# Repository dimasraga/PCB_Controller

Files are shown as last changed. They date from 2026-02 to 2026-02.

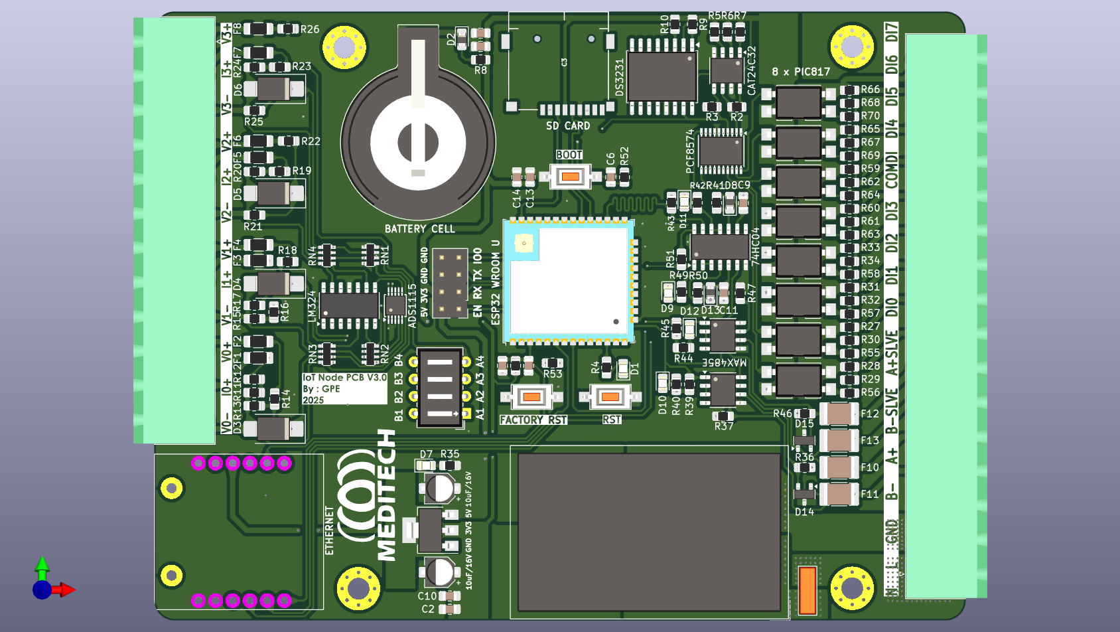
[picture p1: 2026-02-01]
3D PCB.png

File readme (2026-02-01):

# PCB IoT Node - Tugas Akhir

## 📖 Deskripsi Proyek

Repositori ini berisi file desain perangkat keras (Schematic & PCB Layout) dan dokumentasi untuk **IoT Node**. Proyek ini dikembangkan sebagai bagian dari **Tugas Akhir** di Departemen Teknik Elektro, Institut Teknologi Sepuluh Nopember (ITS).

PCB ini dirancang untuk berfungsi sebagai node sensor/aktuator dalam sistem Internet of Things, dengan fokus pada efisiensi daya dan konektivitas yang handal.

## 👤 Penulis

**Dimas Raga**
*   **Institusi:** Teknik Elektro, Institut Teknologi Sepuluh Nopember (ITS)
*   **GitHub:** https://github.com/dimasraga
*   **Instagram:** https://www.instagram.com/dmsragaa

## 📄 Lisensi

Proyek ini dilisensikan di bawah lisensi MIT - lihat file LICENSE untuk detailnya.

---
*Dibuat untuk memenuhi persyaratan Tugas Akhir Teknik Elektro ITS.*

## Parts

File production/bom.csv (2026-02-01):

Designator | Footprint | Quantity | Value | LCSC Part #
BT1 | BatteryHolder_Keystone_103_1x20mm | 1 | Battery_Cell
C1, C12, C4, C5, C6 | 0805 | 5 | 100nF | C1711
C10, C2 | 0805 | 2 | 100n | C1711
C11, C9 | 0805 | 2 | 33p | C541516
C13 | 0805 | 1 | 10uF | C1711
C14 | 0805 | 1 | 0.1uF | C1711
C3 | J_SD_Card-micro_socket_A | 1 | L-KLS1-TF-003-H1.85-R
C7, C8 | CP_Elec_4x5.8 | 2 | 10uF/16V | C59932
D1, D16 | LED_D3.0mm | 2 | Led Red | C2295
D10 | 0805 | 1 | RX | C2296
D11 | 0805 | 1 | TX | C2296
D12 | 0805 | 1 | RX_Slave | C2296
D13, D2, D8 | 0805 | 3 | 1N4148 | C85057
D14, D15 | SOT-23 | 2 | SM712_SOT23 | C32677
D3, D4, D5, D6 | D_SMB_Handsoldering | 4 | TVS_SMBJ28A | C113997
D7 | LED_D3.0mm | 1 | LED | C2297
D9 | 0805 | 1 | TX_Slave | C2296
F1, F2, F3, F4, F5, F6, F7, F8 | 1206 | 8 | 150 mA | C20797
F10, F11, F12, F13 | 1812 | 4 | Fuse_Small | C12430
F9 | C_Rect_L7.0mm_W2.5mm_P5.00mm | 1 | 1A/250VAC
J1 | PhoenixContact_MSTBA_2,5_16-G-5,08_1x16_P5.08mm_Horizontal | 1 | Screw_Terminal_01x16
J3 | PinHeader_2x04_P2.54mm_Vertical | 1 | UPLOADER
J4 | PhoenixContact_MSTBA_2,5_12-G-5,08_1x12_P5.08mm_Horizontal | 1 | Screw_Terminal_01x12
PS1 | Converter_ACDC_Hi-Link_HLK-5Mxx | 1 | HLK-5M05 | C209907
R1, R36, R37, R46, R47, R52, R53 | 0805 | 7 | 10K | C17414
R10, R2, R3, R39, R43, R45, R5, R51, R6, R7, R9 | 0805 | 11 | 4.7K | C26022
R11, R15, R19, R23 | 0805 | 4 | 100 | C2828765
R13, R14, R17, R18, R21, R22, R25, R26 | 0805 | 8 | 510k | C17733
R27, R28, R31, R33, R59, R60, R65, R66 | 0805 | 8 | 1M | C26115
R29, R30, R32, R34, R55, R56, R57, R58, R61, R62, R63, R64, R67, R68, R69, R70 | 0805 | 16 | 470 | C317246
R35, R4, R54, R8 | 0805 | 4 | 200 | C17540
R38, R48 | 1206 | 2 | 120 | C17909
R40, R42, R44, R49 | 0805 | 4 | 2.4k | C17526
R41, R50 | 0805 | 2 | 56k | C137509
RN1, RN2, RN3, RN4 | R_Array_Convex_4x0603 | 4 | 10k
SW1 | SW_SPST_CK_RS282G05A3 | 1 | RST | C231329
SW2 | SW_DIP_SPSTx04_Slide_6.7x11.72mm_W7.62mm_P2.54mm_LowProfile | 1 | SW_DIP_x04 | C840579
SW3 | SW_SPST_CK_RS282G05A3 | 1 | BOOT | C231329
SW4 | SW_Tactile_SPST_Angled_PTS645Vx58-2LFS | 1 | FACTORY RST | C231329
U1 | ESP32-WROOM-32U | 1 | ESP32-WROOM-32U | C328062
U11 | SOT-223-3_TabPin2 | 1 | AMS1117-33 | C6186
U12 | SSOP-20_4.4x6.5mm_P0.65mm | 1 | PCF8574ATS
U13 | TSSOP-10_3x3mm_P0.5mm | 1 | ADS1115IDGS | C37593
U14, U16 | SOIC-8_3.9x4.9mm_P1.27mm | 2 | MAX485E | C19738
U15 | SOIC-14_3.9x8.7mm_P1.27mm | 1 | 74HC04 | C6811
U17, U5 | SMDIP-4_W9.53mm_Clearance8mm | 2 | PC817 | C2833077
U18, U19, U20, U6, U7, U8 | SMDIP-4_W9.53mm_Clearance8mm | 6 | PIC817 | C2833077
U2 | SOIC-8_3.9x4.9mm_P1.27mm | 1 | CAT24C32WI-G | C81193
U3 | SOIC-16W_7.5x10.3mm_P1.27mm | 1 | DS3231SN# | C9866
U4 | SOIC-14_L8.7-W3.9-P1.27-LS6.0-BL | 1 | LM324 | C7943
U9 | W5500 | 1 | W5500_V2

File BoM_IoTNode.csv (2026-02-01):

Reference | Value | Footprint | Qty
BT1 | Battery_Cell | Battery:BatteryHolder_ComfortableElectronic_CH273-2450_1x2450 | 1
C1,C4,C5,C12 | 100nF | -- mixed values -- | 4
C2,C10 | 100n | Capacitor_SMD:C_0805_2012Metric_Pad1.18x1.45mm_HandSolder | 2
C3 | L-KLS1-TF-003-H1.85-R | Connector_Card:J_SD_Card-micro_socket_A | 1
C7,C8 | 10uF/16V | Capacitor_SMD:CP_Elec_4x5.8 | 2
C9,C11 | 33p | Capacitor_SMD:C_0805_2012Metric_Pad1.18x1.45mm_HandSolder | 2
D1 | Led Red | LED_SMD:LED_0805_2012Metric | 1
D2,D8,D13 | 1N4148 | Diode_THT:D_DO-35_SOD27_P7.62mm_Horizontal | 3
D3,D4,D5,D6 | TVS_SMBJ28A | Diode_SMD:D_SMB_Handsoldering | 4
D7 | LED | LED_SMD:LED_0805_2012Metric | 1
D9 | TX_Slave | LED_SMD:LED_0805_2012Metric | 1
D10 | RX | LED_SMD:LED_0805_2012Metric | 1
D11 | TX | LED_SMD:LED_0805_2012Metric | 1
D12 | RX_Slave | LED_SMD:LED_0805_2012Metric | 1
D14,D15 | SM712_SOT23 | Package_TO_SOT_SMD:SOT-23 | 2
F1,F2,F3,F4,F5,F6,F7,F8 | 150 mA | Resistor_SMD:R_1206_3216Metric_Pad1.30x1.75mm_HandSolder | 8
F9 | 1A/250VAC | Capacitor_THT:C_Rect_L7.0mm_W2.5mm_P5.00mm | 1
F10,F11,F12,F13 | Fuse_Small | Fuse:Fuse_1812_4532Metric_Pad1.30x3.40mm_HandSolder | 4
J2 | USB_B_Mini | Connector_USB:USB_Mini-B_Lumberg_2486_01_Horizontal | 1
J3,J4 | Screw_Terminal_01x12 | Connector_Phoenix_MSTB:PhoenixContact_MSTBA_2,5_12-G-5,08_1x12_P5.08mm_Horizontal | 2
PS1 | HLK-5M05 | IC SOIC:CONV_HLK-5M05 | 1
Q1,Q2 | BC817 | Package_TO_SOT_SMD:SOT-23 | 2
R1,R54 | 10K | Resistor_SMD:R_0805_2012Metric | 2
R2,R3,R5,R6,R7,R9,R10 | 4.7K | Resistor_SMD:R_0805_2012Metric | 7
R4,R8,R35 | 200 | -- mixed values -- | 3
R11,R15,R19,R23 | 240 | Resistor_SMD:R_0805_2012Metric_Pad1.20x1.40mm_HandSolder | 4
R12,R16,R24 | 10 | Resistor_SMD:R_0805_2012Metric_Pad1.20x1.40mm_HandSolder | 3
R13,R14,R17,R18,R21,R22,R25,R26 | 510k | Resistor_SMD:R_0805_2012Metric_Pad1.20x1.40mm_HandSolder | 8
R27,R28,R31,R33,R59,R60,R65,R66 | 1M | Resistor_SMD:R_0805_2012Metric | 8
R29,R30,R32,R34,R55,R56,R57,R58,R61,R62,R63,R64,R67,R68,R69,R70 | 470 | Resistor_SMD:R_0805_2012Metric | 16
R36,R37,R46,R47,R52,R53,RN1,RN2,RN3,RN4 | 10k | -- mixed values -- | 10
R38,R48 | 120 | Resistor_SMD:R_1206_3216Metric_Pad1.30x1.75mm_HandSolder | 2
R39,R43,R45,R51 | 4.7k | Resistor_SMD:R_0805_2012Metric_Pad1.20x1.40mm_HandSolder | 4
R40,R42,R44,R49 | 2.4k | Resistor_SMD:R_0805_2012Metric_Pad1.20x1.40mm_HandSolder | 4
R41,R50 | 56k | Resistor_SMD:R_0805_2012Metric_Pad1.20x1.40mm_HandSolder | 2
SW1,SW3 | SW_SPST | Button_Switch_SMD:SW_SPST_B3U-1000P | 2
SW2 | SW_DIP_x04 | Button_Switch_THT:SW_DIP_SPSTx04_Slide_6.7x11.72mm_W7.62mm_P2.54mm_LowProfile | 1
U1 | ESP32-WROOM-32U | RF_Module:ESP32-WROOM-32U | 1
U2 | CAT24C32WI-G | IC SOIC:SOIC127P600X175-8N | 1
U3 | DS3231SN# | IC SOIC:SOIC127P1032X265-16N | 1
U4 | LM324 | IC SOIC:SOIC127P600X175-14N | 1
U5,U17 | PC817 | Package_DIP:SMDIP-4_W9.53mm_Clearance8mm | 2
U6,U7,U8,U18,U19,U20 | PIC817 | Package_DIP:SMDIP-4_W9.53mm_Clearance8mm | 6
U9 | W5500_V2 | TTL to RS485:W5500 | 1
U10 | CH340C | Package_SO:SOIC-16_3.9x9.9mm_P1.27mm | 1
U11 | AMS1117-33 | Package_TO_SOT_SMD:SOT-223-3_TabPin2 | 1
U12 | PCF8574ATS | Package_SO:SSOP-20_4.4x6.5mm_P0.65mm | 1
U13 | ADS1115IDGS | Package_SO:TSSOP-10_3x3mm_P0.5mm | 1
U14,U16 | MAX485E | Package_SO:SOIC-8_3.9x4.9mm_P1.27mm | 2
U15 | 74HC04 | Package_SO:SOIC-14_3.9x8.7mm_P1.27mm | 1

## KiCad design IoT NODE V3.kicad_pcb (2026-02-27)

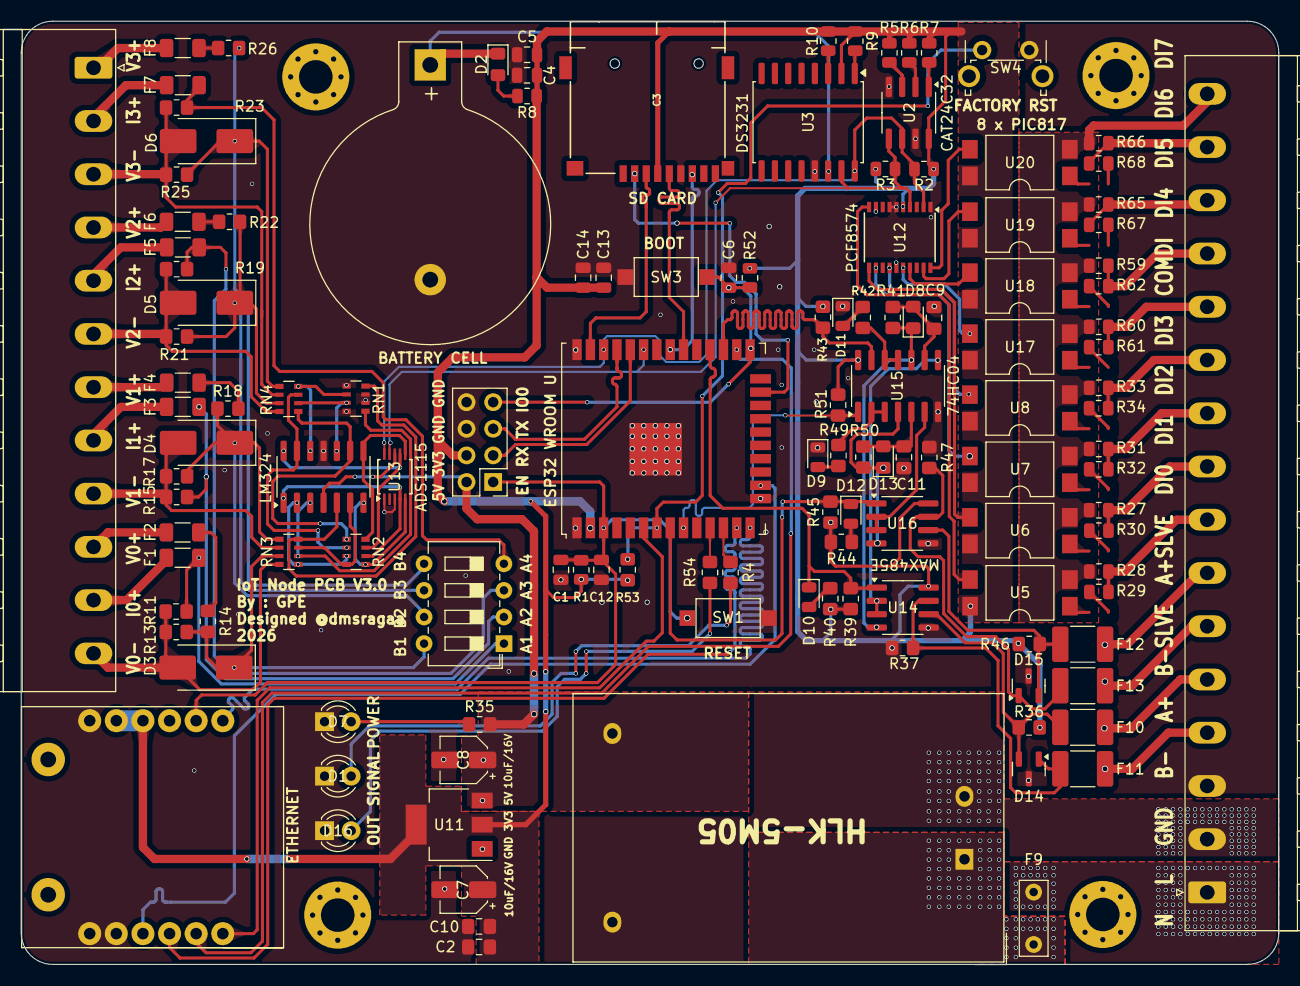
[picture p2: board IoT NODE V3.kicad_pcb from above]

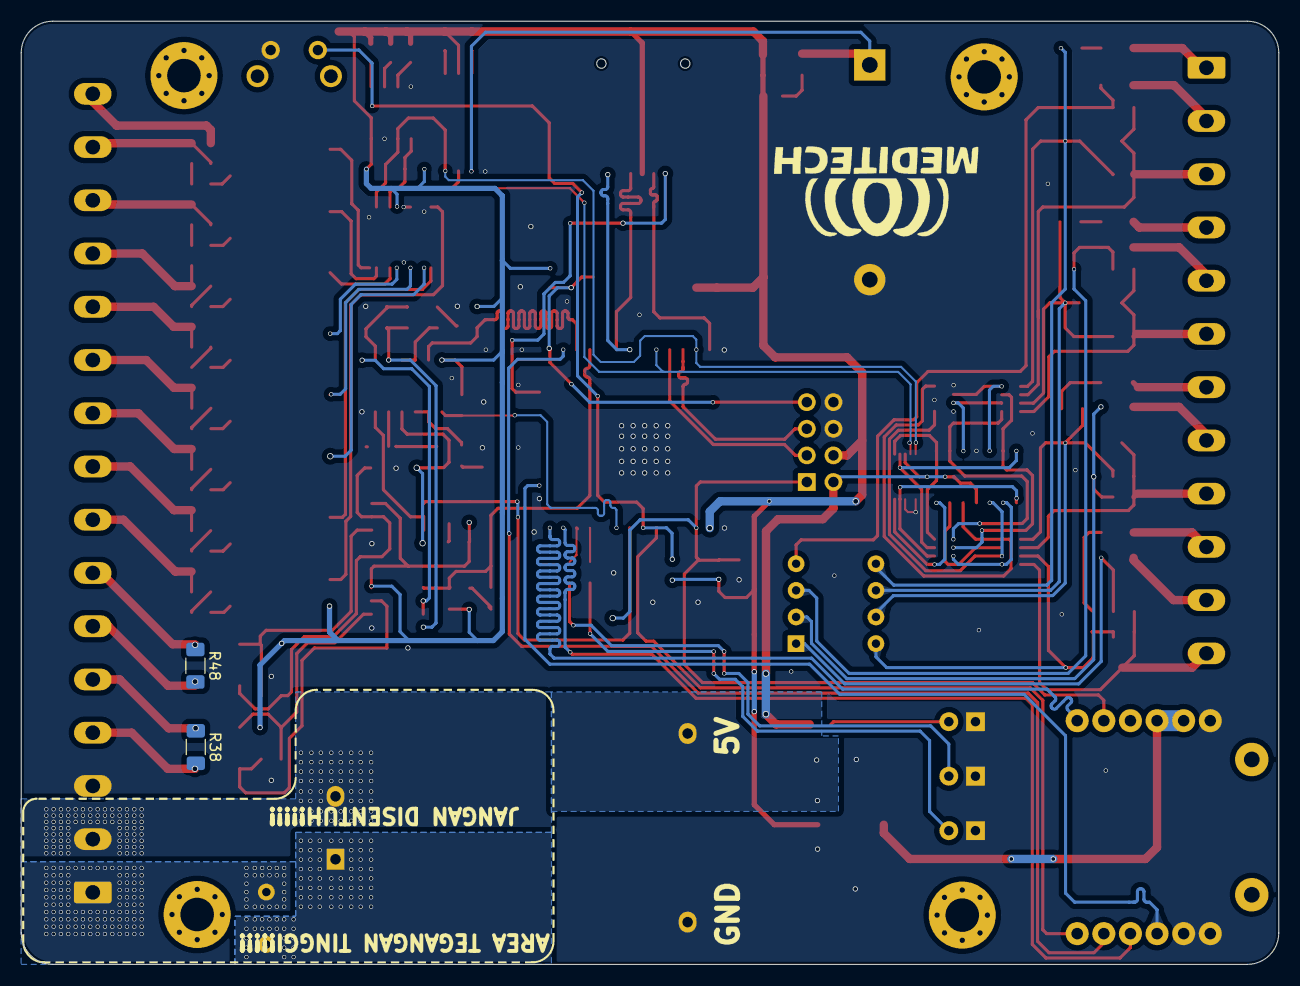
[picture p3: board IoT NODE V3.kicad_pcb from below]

Board: 2 copper layers, 120.0 x 90.0 mm, 137 parts (2 on the bottom side), 119 nets.

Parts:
BT1: Battery_Cell; BatteryHolder_Keystone_103_1x20mm
C1, C4, C5, C6, C12: 100nF; C_0805_2012Metric
C2, C10: 100n; C_0805_2012Metric_Pad1.18x1.45mm_HandSolder
C3: L-KLS1-TF-003-H1.85-R; J_SD_Card-micro_socket_A
C7, C8: 10uF/16V; CP_Elec_4x5.8
C9, C11: 33p; C_0805_2012Metric_Pad1.18x1.45mm_HandSolder
C13: 10uF; C_0805_2012Metric
C14: 0.1uF; C_0805_2012Metric
D1, D16: Led Red; LED_D3.0mm
D2, D8, D13: 1N4148; D_0805_2012Metric_Pad1.15x1.40mm_HandSolder
D3, D4, D5, D6: TVS_SMBJ28A; D_SMB_Handsoldering
D7: LED; LED_D3.0mm
D9: TX_Slave; LED_0805_2012Metric
D10: RX; LED_0805_2012Metric
D11: TX; LED_0805_2012Metric
D12: RX_Slave; LED_0805_2012Metric
D14, D15: SM712_SOT23; SOT-23
F1, F2, F3, F4, F5, F6, F7, F8: 150 mA; R_1206_3216Metric_Pad1.30x1.75mm_HandSolder
F9: 1A/250VAC; C_Rect_L7.0mm_W2.5mm_P5.00mm
F10, F11, F12, F13: Fuse_Small; C_1812_4532Metric_Pad1.57x3.40mm_HandSolder
H1, H2, H3, H4: MountingHole; MountingHole_3.2mm_M3_Pad_Via
J1: Screw_Terminal_01x16; PhoenixContact_MSTBA_2,5_16-G-5,08_1x16_P5.08mm_Horizontal
J3: UPLOADER; PinHeader_2x04_P2.54mm_Vertical
J4: Screw_Terminal_01x12; PhoenixContact_MSTBA_2,5_12-G-5,08_1x12_P5.08mm_Horizontal
PS1: HLK-5M05; Converter_ACDC_Hi-Link_HLK-5Mxx
R1, R52: 10K; R_0805_2012Metric
R2, R3, R5, R6, R7, R9, R10: 4.7K; R_0805_2012Metric
R4, R35, R54: 200; R_0805_2012Metric_Pad1.20x1.40mm_HandSolder
R8: 200; R_0805_2012Metric
R11, R15, R19, R23: 100; R_0805_2012Metric_Pad1.20x1.40mm_HandSolder
R13, R14, R17, R18, R21, R22, R25, R26: 510k; R_0805_2012Metric_Pad1.20x1.40mm_HandSolder
R27, R28, R31, R33, R59, R60, R65, R66: 1M; R_0805_2012Metric
R29, R30, R32, R34, R61, R62, R67, R68: 4k3; R_0805_2012Metric
R36, R37, R46, R47: 10k; R_0805_2012Metric_Pad1.20x1.40mm_HandSolder
R38, R48: 120; R_1206_3216Metric_Pad1.30x1.75mm_HandSolder
R39, R43, R45, R51: 4.7k; R_0805_2012Metric_Pad1.20x1.40mm_HandSolder
R40, R42, R44, R49: 2.4k; R_0805_2012Metric_Pad1.20x1.40mm_HandSolder
R41, R50: 56k; R_0805_2012Metric_Pad1.20x1.40mm_HandSolder
R53: 10K; R_0805_2012Metric_Pad1.20x1.40mm_HandSolder
RN1, RN2, RN3, RN4: 10k; R_Array_Convex_4x0603
SW1: RST; SW_SPST_CK_RS282G05A3
SW2: SW_DIP_x04; SW_DIP_SPSTx04_Slide_6.7x11.72mm_W7.62mm_P2.54mm_LowProfile
SW3: BOOT; SW_SPST_CK_RS282G05A3
SW4: FACTORY RST; SW_Tactile_SPST_Angled_PTS645Vx58-2LFS
U1: ESP32-WROOM-32U
U2: CAT24C32WI-G; SOIC-8_3.9x4.9mm_P1.27mm
U3: DS3231SN#; SOIC-16W_7.5x10.3mm_P1.27mm
U4: LM324; SOIC-14_L8.7-W3.9-P1.27-LS6.0-BL
U5, U17: PC817; SMDIP-4_W9.53mm_Clearance8mm
U6, U7, U8, U18, U19, U20: PIC817; SMDIP-4_W9.53mm_Clearance8mm
U9: W5500_V2; W5500
U11: AMS1117-33; SOT-223-3_TabPin2
U12: PCF8574ATS; SSOP-20_4.4x6.5mm_P0.65mm
U13: ADS1115IDGS; TSSOP-10_3x3mm_P0.5mm
U14, U16: MAX485E; SOIC-8_3.9x4.9mm_P1.27mm
U15: 74HC04; SOIC-14_3.9x8.7mm_P1.27mm

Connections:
+3.3V: C2.1, C3.4, C4.1, C5.1, C7.1, C10.1, C13.1, C14.1, J3.4, R1.2, R2.2, R3.2, R5.2, R6.2, R7.2, R8.2, R9.1, R10.1, R36.1, R39.1, R40.1, R43.1, R44.1, R45.1, R46.1, R51.1, R52.2, R53.2, U1.2 (VDD), U2.8 (VCC), U3.2 (VCC), U5.4, U6.4, U7.4, U8.4, U9.10 (3.3V), U9.11 (3.3V), U11.2 (VO), U12.5 (VDD), U14.8 (VCC), U15.14 (VCC), U16.8 (VCC), U17.4, U18.4, U19.4, U20.4
+5V: C8.1, J3.2, PS1.4 (+VO), R35.1, U4.4 (V+), U11.3 (VI), U13.8 (VDD)
/A+: F10.2, J1.5, R38.1
/A+_Slave: F12.2, J1.7, R48.1
/Analog 0: RN2.2 (R2.1), U4.1, U13.4 (AIN0)
/Analog 1: RN2.1 (R1.1), U4.7, U13.5 (AIN1)
/Analog 2: RN2.4 (R4.1), U4.8, U13.6 (AIN2)
/Analog 3: RN2.3 (R3.1), U4.14, U13.7 (AIN3)
/AnalogInput/A01: F1.2, R11.2, SW2.1
/AnalogInput/A02: F3.2, R15.2, SW2.2
/AnalogInput/A03: F5.2, R19.2, SW2.3
/AnalogInput/A04: F7.2, R23.2, SW2.4
/AnalogInput/B01: D3.1 (K), R13.2, R14.1, RN3.7 (R2.2), SW2.8
/AnalogInput/B02: D4.1 (K), R17.2, R18.1, RN3.5 (R4.2), SW2.7
/AnalogInput/B03: D5.1 (K), R21.2, R22.1, RN4.7 (R2.2), SW2.6
/AnalogInput/B04: D6.1 (K), R25.2, R26.1, RN4.5 (R4.2), SW2.5
/B-: F11.2, J1.4, R38.2
/B-_Slave: F13.2, J1.6, R48.2
/COM DI: J1.16, R27.1, R28.1, R31.1, R33.1, R59.1, R60.1, R65.1, R66.1, U5.2, U6.2, U7.2, U8.2, U17.2, U18.2, U19.2, U20.2
/DI0: J1.8, R28.2, R29.1
/DI1: J1.9, R27.2, R30.1
/DI2: J1.10, R31.2, R32.1
/DI3: J1.11, R33.2, R34.1
/DI4: J1.12, R60.2, R61.1
/DI5: J1.13, R59.2, R62.1
/DI6: J1.14, R65.2, R67.1
/DI7: J1.15, R66.2, R68.1
/I0+: F1.1, J4.11
/I1+: F3.1, J4.8
/I2+: F5.1, J4.5
/I3+: F7.1, J4.2
/L: J1.2, PS1.2 (AC(N))
/N: F9.1, J1.1
/RX_Slave: D12.1 (K), R45.2, U1.8 (IO32), U16.1 (RO)
/Rx: D10.1 (K), R39.2, U1.28 (IO17), U14.1 (RO)
/SPI_CLK: U1.13 (IO14), U9.4 (SCLK)
/SPI_MISO: U1.14 (IO12), U9.7 (MISO)
/SPI_MOSI: U1.16 (IO13), U9.3 (MOSI)
/TX_Slave: R51.2, U1.9 (IO33), U15.1
/Tx: R43.2, U1.27 (IO16), U15.13
/V0+: F2.1, J4.10
/V0-: D3.2 (A), J4.12, R11.1, R13.1, RN3.8 (R1.2)
/V1+: F4.1, J4.7
/V1-: D4.2 (A), J4.9, R15.1, R17.1, RN3.6 (R3.2)
/V2+: F6.1, J4.4
/V2-: D5.2 (A), J4.6, R19.1, R21.1, RN4.8 (R1.2)
/V3+: F8.1, J4.1
/V3-: D6.2 (A), J4.3, R23.1, R25.1, RN4.6 (R3.2)
/nINT: U1.6 (IO34), U9.6 (nINT)
/nSS: U1.26 (IO4), U9.5 (nSS)
CLK: C3.5, U1.30 (IO18)
D5_MICRO_SD: C3.2, U1.23 (IO15)
Digital Input 0: U5.3, U12.10 (P0)
Digital Input 1: U6.3, U12.11 (P1)
Digital Input 2: U7.3, U12.12 (P2)
Digital Input 3: U8.3, U12.14 (P3)
Digital Input 4: U12.16 (P4), U17.3
Digital Input 5: U12.17 (P5), U18.3
Digital Input 6: U12.19 (P6), U19.3
Digital Input 7: U12.20 (P7), U20.3
EN: C1.1, C12.1, J3.1, R1.1, SW1.1 (A), U1.3 (EN), U9.8 (nRST)
Earth_Protective: BT1.2 (-), C1.2, C2.2, C3.6, C4.2, C5.2, C6.2, C7.2, C8.2, C9.2, C10.2, C11.2, C12.2, C13.2, C14.2, D1.1 (K), D7.1 (K), D9.1 (K), D11.1 (K), D14.3 (common), D15.3 (common), D16.1 (K), J1.3, J3.6, J3.8, PS1.3 (-VO), R37.2, R47.2, RN1.1 (R1.1), RN1.4 (R4.1), RN1.6 (R3.2), RN1.7 (R2.2), SW1.2 (B), SW3.2 (B), SW4.2 (B), U1.1 (GND), U1.15 (GND), U1.38 (GND), U1.39 (GND), U2.4 (VSS), U2.7 (WP), U3.13 (GND), U4.11 (V-), U9.1 (GND), U9.2 (GND), U9.12 (GND), U11.1 (GND), U12.1 (~INT), U12.6 (A0), U12.7 (A1), U12.9 (A2), U12.15 (VSS), U13.1 (ADDR), U13.3 (GND), U14.5 (GND), U15.7 (GND), U16.5 (GND)
FACTORY: R53.1, SW4.1 (A), U1.7 (IO35)
IO0: C6.1, J3.7, R52.1, SW3.1 (A), U1.25 (IO0)
LED_OUT: R54.2, U1.11 (IO26)
LED_SIG: R4.2, U1.12 (IO27)
MISO: C3.7, U1.31 (IO19)
MOSI: C3.3, U1.37 (IO23)
unnamed: D1.2 (A), R4.1
unnamed: D2.2 (A), R8.1
unnamed: D7.2 (A), R35.2
unnamed: C9.1, D8.2 (A), R41.2, U15.9
unnamed: D8.1 (K), R41.1, U14.4 (DI), U15.10
unnamed: D9.2 (A), R49.2
unnamed: D10.2 (A), R40.2
unnamed: D11.2 (A), R42.2
unnamed: D12.2 (A), R44.2
unnamed: C11.1, D13.2 (A), R50.2, U15.5
unnamed: D13.1 (K), R50.1, U15.4, U16.4 (DI)
unnamed: D14.1 (A1), F11.1, R37.1, U14.7 (B)
unnamed: D14.2 (A2), F10.1, R36.2, U14.6 (A)
unnamed: D15.1 (A1), F13.1, R47.1, U16.7 (B)
unnamed: D15.2 (A2), F12.1, R46.2, U16.6 (A)
unnamed: D16.2 (A), R54.1
unnamed: F2.2, R14.2
unnamed: F4.2, R18.2
unnamed: F6.2, R22.2
unnamed: F8.2, R26.2
unnamed: F9.2, PS1.1 (AC(L))
unnamed: R29.2, U5.1
unnamed: R30.2, U6.1
unnamed: R32.2, U7.1
unnamed: R34.2, U8.1
unnamed: R42.1, U15.11, U15.12
unnamed: R49.1, U15.2, U15.3
unnamed: R61.2, U17.1
unnamed: R62.2, U18.1
unnamed: R67.2, U19.1
unnamed: R68.2, U20.1
unnamed: RN1.8 (R1.2), RN3.4 (R4.1), U4.5 (+)
unnamed: RN1.2 (R2.1), RN4.4 (R4.1), U4.12 (+)
unnamed: RN1.3 (R3.1), RN4.2 (R2.1), U4.10 (+)
unnamed: RN1.5 (R4.2), RN3.2 (R2.1), U4.3 (+)
unnamed: RN2.8 (R1.2), RN3.3 (R3.1), U4.6 (-)
unnamed: RN2.7 (R2.2), RN3.1 (R1.1), U4.2 (-)
unnamed: RN2.6 (R3.2), RN4.3 (R3.1), U4.13 (-)
unnamed: RN2.5 (R4.2), RN4.1 (R1.1), U4.9 (-)
unnamed: R7.1, U2.1 (A0)
unnamed: R6.1, U2.2 (A1)
unnamed: R5.1, U2.3 (A2)
unnamed: R9.2, U3.1 (32KHZ)
unnamed: R10.2, U3.3 (SQW/~INT)
unnamed: U14.2 (~RE), U14.3 (DE), U15.8
unnamed: U15.6, U16.2 (~RE), U16.3 (DE)
RXD: J3.3, U1.34 (RXD0/IO3)
SCL: R2.1, U1.36 (IO22), U2.6 (SCL), U3.16 (SCL), U12.2 (SCL), U13.10 (SCL)
SDA: R3.1, U1.33 (IO21), U2.5 (SDA), U3.15 (SDA), U12.4 (SDA), U13.9 (SDA)
TXD: J3.5, U1.35 (TXD0/IO1)
V_BAT: BT1.1 (+), D2.1 (K), U3.14 (VBAT)
